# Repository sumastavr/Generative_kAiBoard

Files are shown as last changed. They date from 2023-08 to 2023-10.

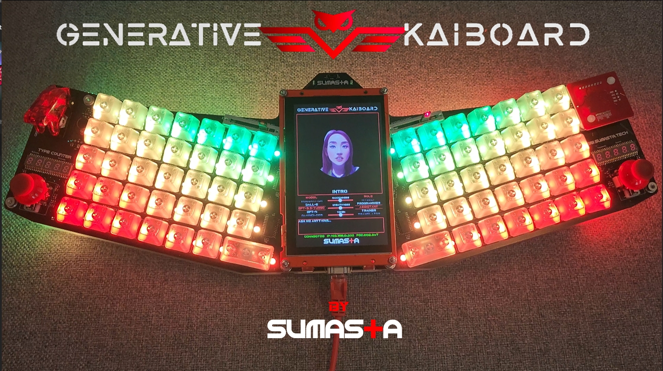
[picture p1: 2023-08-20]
Media/2023-08-20 00 04 33.jpg

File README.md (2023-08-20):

# Generative_kAiBoard 

"Introducing the "Generative KAiboard": a revolutionary fusion of cutting-edge technology and design. This keyboard redefines the boundaries of user interaction, boasting a plethora of advanced features, elegant design, AI-powered intelligence and virtual assistance that transcend traditional input devices. Crafted with an emphasis on aesthetics and functionality, the keyboard houses 70 Cherry MX switches with an impressive 100 million keystroke guarantee, ensuring both responsiveness and durability. Its versatility is highlighted by an array of 80 addressable pixel RGB LEDs, creating captivating lighting effects within a translucent 3D-printed housing.

The keyboard seamlessly integrates an 8x8 multizone time-of-flight sensor, ushering in a new era of presence and gesture detection. Additionally, a dedicated co-processor enables Bluetooth HID connections to various devices, while an NFC tag reader enhances security through authentication. Safety and security are paramount, with meticulous considerations in the PoE design ensuring consistent and reliable power delivery.

The "Generative KAiboard" transcends conventional interfaces, featuring a mono speaker for audio feedback and alerts. Its centerpiece is a 5-inch LCD display with a capacitive touch screen, offering a dynamic hub of information and interaction. Complemented by 60 RGB LEDs along the sides, the keyboard creates an enchanting symphony of light diffused through its translucent housing. The integration of a Wiznet W5300 shield and STM32F429 Nucleo board ensures future-proof modularity, enabling seamless upgrades and adaptability to evolving technologies. This extraordinary convergence of innovation, design, and intelligence marks the dawn of the "Generative KAiboard," a catalyst for the next generation of human-computer interaction." - Generative kAiboard.











The journey of crafting the Generative kAiboard has been an extraordinary endeavor that encapsulates both passion and persistence. Within a span of just five weeks, fueled by countless sleepless nights and unwavering dedication, I have breathed life into this intricate creation. The process has been a fusion of technical prowess and artistic inspiration, resulting in a masterpiece that harmoniously blends cutting-edge technology with a touch of imagination.

Every line of code, every connection meticulously soldered, every sleep-deprived night spent fine-tuning details – all of these have converged to birth a tangible manifestation of innovation. The Generative kAiboard is not just a keyboard; it's a testament to the capabilities of human creativity and the relentless pursuit of turning imagination into reality. As I now present the culmination of this journey, I invite you to explore, experiment, and immerse yourself in the possibilities this keyboard offers. With each keystroke, may it remind you of the remarkable journey it took to bring this vision to life – a journey characterized by determination, sleepless nights, and the sheer joy of creation.

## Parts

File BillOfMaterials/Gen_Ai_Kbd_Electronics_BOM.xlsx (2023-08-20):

Line # | Name | Description | Designator | Revision ID | Revision Status | Quantity | Ordered Status | Manufacturer 1 | Manufacturer Part Number 1 | Manufacturer Lifecycle 1 | Supplier 1 | Supplier Part Number 1 | Supplier Unit Price 1 | Supplier Subtotal 1
 | 885012206114 | WCAP-CSGP Multilayer Ceramic Chip Capacitor, General Purpose, size 0603, X7R, 10nF, 100VDC | C1 | CMP-007-000667-1 | Up to date | 1 | Stock
 | 885012008079 | WCAP-CSGP Multilayer Ceramic Chip Capacitor, General Purpose, size 1206, NP0, 10nF, 100VDC | C2, C3 | CMP-007-000324-1 | Up to date | 2 | Stock
 | 875575357008 | 875575357008 Cap, 470Uf, 16V, Alu Elec, Hybrid, Smd Rohs Compliant: Yes |Wurth Elektronik 875575357008 | C4, C10 | CMP-03913-134709151-1 | Up to date | 2 | Ordered 4 | Wurth Electronics | 875575357008 | Unknown | Digi-Key | 732-875575357008CT-ND | 3.19 | 6.38
 | 885012206095 | WCAP-CSGP Multilayer Ceramic Chip Capacitor, General Purpose, size 0603, X7R, 100nF, 50VDC | C5, C11, C13, C47, C51, C52, C53, C54, C57, C58, C59, C61, C63, C65, C67, C69, C70, C71, C72, C74, C76, C79, C81 | CMP-007-000655-1 | Up to date | 23 | Stock
 | 885012206020 | WCAP-CSGP Multilayer Ceramic Chip Capacitor, General Purpose, size 0603, X7R, 100nF, 10VDC | C6, C7, C8, C9 | CMP-007-000576-1 | Up to date | 4 | Stock
 | 885012106006 | WCAP-CSGP Multilayer Ceramic Chip Capacitor, General Purpose, size 0603, X5R, 10µF, 6.3VDC | C12, C46, C60, C62, C64, C66, C68, C75, C77, C80, C82 | CMP-007-000403-1 | Up to date | 11 | Stock
 | 885012205018 | WCAP-CSGP Multilayer Ceramic Chip Capacitor, General Purpose, size 0402, X7R, 100nF, 10VDC | C14, C15, C16, C17, C18, C19, C20, C21, C22, C23, C24, C25, C26, C27, C28, C29, C30, C31, C32, C33, C34, C35, C36, C37, C38, C39, C40, C41, C42, C43 | CMP-007-000501-1 | Up to date | 30 | Stock
 | 885012206051 | 885012206051 Cap Cer 0.68UF 16V X7R 0603 | C44, C45, C48, C55, C56, C73, C78, C84 | CMP-03913-53914760-1 | Up to date | 8 | Stock | Wurth Electronics | 885012206051 | Volume Production | Farnell | 2534025 | 0.07158 | 0.71579
 | 885342211008 | 885342211008 4700PF 2000V X7R 1812 10% - Multilayer Ceramic Capacitors | C49, C50, C83 | CMP-03913-89205791-1 | Up to date | 3 | Ordered 9 | Wurth Electronics | 885342211008 | Unknown | Farnell | 2812616 | 0.78494 | 2.35
 | ABS10A-13 | BRIDGE RECT 1PHASE 1KV 1A 4SOPA | D1, D3 | CMP-12791-000054-1 | Up to date | 2 | Cart Digikey 14 | Diodes | ABS10A-13 | Unknown | Arrow Electronics | ABS10A-13 | 0.2889 | 0.5778
 | 824541581 | 824541581 TVS diode [Würth Elektronik] 824541581 TVS diode | D2 | CMP-03913-71101705-1 | Up to date | 1 | Ordered 4 | Wurth Electronics | 824541581 | Volume Production | Digi-Key | 732-9823-1-ND | 0.89 | 0.89
 | 824045817 | 824045817 Tvs Diode, Unidir, 7V, Dfn1610 Rohs Compliant: Yes |Wurth Elektronik 824045817 | D4, D5, D6, D7, D8, D9, D10, D11, D12, D13, D14, D15, D16 | CMP-03913-128281014-1 | Up to date | 13 | Ordered 20 | Wurth Electronics | 824045817 | Unknown | Mouser | 710-824045817 | 0.567 | 7.37
 | 1N4148WS | DIODE GEN PURP 75V 150MA SOD323F | D17, D21, D22 | CMP-07163-000040-1 | Up to date | 3 | Cart Digikey 25 | ON Semiconductor / Fairchild | 1N4148WS | Volume Production | Newark | 08AK7787 | 0.022 | 0.066
 | 82400102 |  | D18 | CMP-1486-00007-2 | Up to date | 1 | Ordered 4 | Wurth Electronics | 82400102 | Volume Production | Mouser | 710-82400102 | 0.85 | 0.85
 | 155124M172400 | 155124M172400 Wl-sfsw SMT Full-color Side View | D19, D20 | CMP-03913-133884675-1 | Up to date | 2 | Ordered 8 | Wurth Electronics | 155124M172400 | Unknown | Digi-Key | 732-155124M172400CT-ND | 0.58 | 1.16
 | 157102S12800 | 157102S12800 WL-S7DS 7 Segments Display SMT Single Digit | DS1, DS2, DS3, DS4, DS5, DS6, DS7, DS8, DS9, DS10 | CMP-03913-133884679-1 | Up to date | 10 | Ordered 14 | Wurth Electronics | 157102S12800 | Unknown | Digi-Key | 732-157102S12800CT-ND | 3.14 | 31.4
 | 74279246 | WE-CBF SMT EMI Suppression Ferrite Bead, size 1806, 1000Ohm, 1.5A | FB1, FB2, FB3, FB6, FB7, FB8 | CMP-021-000088-1 | Up to date | 6 | Ordered 10 | Wurth Electronics | 74279246 | Unknown | Digi-Key | 732-74279246CT-ND | 0.3 | 1.8
 | 742792907 |  | FB4 | CMP-0220-00071-2 | Up to date | 1 | Ordered 3 | Wurth Electronics | 742792907 | Volume Production | Mouser | 710-742792907 | 2.86 | 2.86
 | 7427927311 |  | FB5, FB9, FB14, FB28, FB29 | CMP-0220-00132-2 | Up to date | 5 | Ordered 10 | Wurth Electronics | 7427927311 | Volume Production | Digi-Key | 732-2366-1-ND | 0.18 | 0.9
 | 742792651 |  | FB10, FB11, FB15, FB16, FB17, FB18, FB19, FB20, FB21, FB22, FB23, FB24, FB25, FB26, FB27 | CMP-0220-00181-3 | Up to date | 15 | Ordered 20 | Wurth Electronics | 742792651 | Volume Production | Mouser | 710-742792651 | 0.18 | 2.7
 | 61003621821 |  | J1, J2, J4, J5 | CMP-1502-01300-2 | Up to date | 4 | Ordered 6 | Wurth Electronics | 61003621821 | Unknown
 | 629722000214 | Conenctor USB 2.0 Type C Horizontal SMT | J3, J11 | CMP-207978-000003-2 | Up to date | 2 | Ordered 4 | Wurth Electronics | 629722000214 | Unknown | Farnell | 4146212 | 2.91 | 5.82
 | 613002143121 |  | J6, J7 | CMP-1502-01405-2 | Up to date | 2 | NR | Wurth Electronics | 613002143121 | Unknown | Farnell | 3583858 | 0.32393 | 3.24
 | 613003143121 |  | J8 | CMP-1502-01406-2 | Up to date | 1 | NR | Wurth Electronics | 613003143121 | Unknown | Newark | 99AH1112 | 0.399 | 3.99
 | 62200421821 |  | J9, J10, J12 | CMP-1502-01179-2 | Up to date | 3 | NR | Wurth Electronics | 62200421821 | Unknown | Mouser | 710-62200421821 | 0.74 | 2.22
 | 74438367068 | 74438367068 Power Inductor, 6.8Uh, Shielded, 5.7A Rohs Compliant: Yes |Wurth Elektronik 74438367068 | L1 | CMP-03913-130924347-1 | Up to date | 1 | Ordered 4 | Wurth Electronics | 74438367068 | Unknown | Mouser | 710-74438367068 | 2.14 | 2.14
 | 744232090 |  | L2 | CMP-0222-00035-2 | Up to date | 1 | Ordered 4 | Wurth Electronics | 744232090 | Volume Production | Mouser | 710-744232090 | 1.28 | 1.28
 | NX8048P050-011C | Nextion 5.5 Inch LCD | LCD1 | CMP-00028-00007-2 | Up to date | 1 | Stock | B&F Fastener | MPMS0020012PH | Volume Production
 | ESP32-WROOM-DA | WiFi-Modul 802.11/BT 2, 4-2, 5GHz 150Mb/s, dual antenna | MD1 | CMP-021-00008-1 | Up to date | 1 | Cart Digikey 3 | Espressif Systems | ESP32-WROOM-32E(4MB) | Unknown
 | 7466003 | 7466003 WP-SMBU REDCUBE Bush, SMT_open | MP1, MP2, MP3, MP4, MP5, MP6, MP7, MP8, MP9 | CMP-03913-34964368-1 | Up to date | 9 | Ordered 10 | Wurth Electronics | 7466003 | Volume Production | Farnell | 2405984 | 2.23 | 22.32
 | 61300411121 |  | P1, P6 | CMP-1502-01064-2 | Up to date | 2 | NR | Wurth Electronics | 61300411121 | Volume Production | Digi-Key | 732-5317-ND | 0.19 | 0.38
 | 61003621121 |  | P2, P3, P4, P5 | CMP-1502-01049-2 | Up to date | 4 | Ordered 6 | Wurth Electronics | 61003621121 | Volume Production | Mouser | 710-61003621121 | 5.25 | 21
 | 140356145000 | 140356145000 Optocoupler, Transistor, 80V, Sop-4 Rohs Compliant: Yes |Wurth Elektronik 140356145000 | Q1 | CMP-03913-114060666-1 | Up to date | 1 | Ordered 4 | Wurth Electronics | 140356145000 | Unknown | Farnell | 3619699 | 0.35304 | 0.35304
 | UMH3NTN | TRANS 2NPN PREBIAS 0.15W UMT6 | Q2 | CMP-08979-000010-1 | Up to date | 1 | Cart Digikey 10 | Rohm | UMH3NTN | Volume Production | Mouser | 755-UMH3NTN | 0.45 | 0.45
 | BSS123-7-F | MOSFET N-CH 100V 170MA SOT23-3 | Q3, Q4 | CMP-12801-000017-1 | Up to date | 2 | Cart Digikey 15 | Diodes | BSS123-7-F | Volume Production | Mouser | 621-BSS123-F | 0.26 | 0.52
 | RC0603FR-070RL | RES SMD 0 OHM JUMPER 1/10W 0603 | R1, R2, R8, R45, R46 | CMP-2000-06925-2 | Up to date | 5 | Stock | Yageo | RC0603FR-070RL | Volume Production | Newark | 50Y7761 | 0.002 | 0.01
 | RKJXK122400Y | Res POT 10K Ohm 0.0125W (25.4 X 20.7 X 19.3mm) Pin Bracket Mount/Through Hole Tray | R3, R4 | CMP-24118-000005-1 | Up to date | 2 | Cart Mouser | Alps Electric | RKJXK122400Y | Volume Production
 | RC0603FR-07470RL | General Purpose Chip Resistor, 470 Ohm, +/- 1%, -55 to 155 degC, 0603 (1608 Metric), RoHS, Tape and Reel | R5, R6 | CMP-1659-00035-2 | Up to date | 2 | Stock | Yageo | RC0603FR-07470RL | Volume Production | Newark | 75X0155 | 0.003 | 0.006
 | Resistor 10k +/-1% 0603 100 mW | Chip Resistor, 10 KOhm, +/- 1%, 01 W, -55 to 155 degC, 0603 (1608 Metric) | R7, R9, R10, R11, R12, R13, R14, R15, R16, R17, R18, R19, R20, R21, R22, R23, R24, R25, R26, R27, R28, R29, R30, R31, R32, R33, R34, R35, R36, R37, R38, R39, R40, R41, R42, R43, R44, R47, R48, R49, R50 | CMP-009-00017-5 | Up to date | 41 | Stock | Yageo | RC0603FR-0710KL | Volume Production | Newark | 68X3181 | 0.003 | 0.123
 | RC0603FR-075K1L |  | R51, R52, R53, R54 | CMP-2000-04091-1 | Up to date | 4 |  | Yageo | RC0603FR-075K1L | Volume Production | Avnet | 82AH8175 | 0.004 | 0.016
 | YC164-JR-0710KL | RES ARRAY 4 RES 10K OHM 1206 | RN1, RN2, RN3, RN4 | CMP-03411-000003-1 | Up to date | 4 | Cart Digikey 100 | Yageo | YC164-JR-0710KL | Volume Production | Digi-Key | YC164J-10KCT-ND | 0.1 | 0.4
 | EXB-2HV101JV | RES ARRAY 8 RES 100 OHM 1506 | RN5, RN6, RN7, RN8, RN9, RN10, RN11, RN12, RN13, RN14 | CMP-05421-000005-1 | Up to date | 10 | Cart Digikey 25 | Panasonic | EXB-2HV101JV | Volume Production | Farnell | 2060071 | 0.13345 | 1.33
 | MX1A-11NW | Switch Key N.O. SPST 0.01A 12VAC 12VDC 0.58N PC Pins 50000000Cycles Thru-Hole | SW1, SW2, SW3, SW4, SW5, SW6, SW7, SW8, SW9, SW10, SW11, SW12, SW13, SW14, SW15, SW16, SW17, SW18, SW19, SW20, SW21, SW22, SW23, SW24, SW25, SW26, SW27, SW28, SW29, SW30, SW31, SW32, SW33, SW34, SW35, SW36, SW37, SW38, SW39, SW40, SW41, SW42, SW43, SW44, SW45, SW46, SW47, SW48, SW49, SW50, SW51, SW52, SW53, SW54, SW55, SW56, SW57, SW58, SW59, SW60, SW61, SW62, SW63, SW64, SW65, SW66, SW67, SW68, SW69, SW70 | CMP-011-00013-1 | Up to date | 70 | Stock | Cherry | MX1A-11NW | Volume Production | Mouser | 540-MX1A-11NW | 0.776 | 54.32
 | 7499411122A | 7499411122A Rj45 Conn, R/A Jack, 8P8C, 1Port, Th Rohs Compliant: Yes |Wurth Elektronik 7499411122A | T1 | CMP-03913-82944263-1 | Up to date | 1 | Ordered 3 | Wurth Electronics | 7499411122A | Unknown | Mouser | 710-7499411122A | 14.77 | 14.77
 | AG5405 | PoE Module 802.3at | U1 | CMP-019-00052-1 | Up to date | 1 | Cart Mouser | STMicroelectronics | L7805CV-DG | Volume Production | Future Electronics | 8013057 | 0.44 | 0.44
 | CD74HC4067M96 | IC MUX/DEMUX 1X16 24SOIC | U2, U3, U4, U5 | CMP-04901-000007-1 | Up to date | 4 | Cart Mouser | Texas Instruments | CD74HC4067M96 | Volume Production
 | 173950336 | 173950336 WPME-FDSM Fixed Step Down Regulator Module | U6 | CMP-03913-104891430-1 | Up to date | 1 | Ordered 3 | Wurth Electronics | 173950336 | Unknown | Mouser | 710-173950336 | 6.52 | 6.52
 | NUCLEO-F429ZI | STM32F429ZI, mbed-Enabled Development Nucleo-144 STM32F4 ARMÂ® CortexÂ®-M4 MCU 32-Bit Embedded Evaluation Board | U7 | CMP-017-000000-2 | Up to date | 1 | Stock
 | CP2104-F03-GM | IC SGL USB-TO-UART BRIDGE 24QFN | U8 | CMP-0511-00004-2 | Up to date | 1 | Cart Digikey 3 | Silicon Labs | CP2104-F03-GM | Volume Production | Arrow Electronics | CP2104-F03-GM | 2.94 | 2.94
 | SN74LV1T125DBVR | Single Power Supply, Single BUFFER GATE w/ 3-State Output (active low enable), DBV0005A, LARGE T&R | U9, U10, U22, U24, U25 | CMP-0859-00122-3 | Up to date | 5 | Cart Digikey 15 | Texas Instruments | SN74LV1T125DBVR | Volume Production | Arrow Electronics | SN74LV1T125DBVR | 0.5289 | 2.64
 | 74HC595PW,118 | IC SHIFT REGISTER 8BIT 16TSSOP | U11, U13, U14, U15, U16, U17, U18, U19, U20, U21 | CMP-14351-000004-1 | Up to date | 10 | Cart Mouser | Nexperia | 74HC595PW,118 | Volume Production | Newark | 26AC8674 | 0.128 | 1.28
 | VL53L5CX | VL53L5CX - 8X8 Segment, Light, 3D Time-of-Flight _ToF_ Sensor Evaluation Board | U12 | CMP-003-000011-1 | Up to date | 1 | Cart Mouser
 | 24LC1025-I/SM | 1 Mbit, 400kHz, 2.5V, I2C Serial EEPROM, 8-Pin SOIC 208mil, Industrial Temperature | U23 | CMP-0159-00567-1 | Up to date | 1 | Cart Mouser | Microchip | 24LC1025-I/SM | Volume Production | Mouser | 579-24LC1025-I/SM | 3.83 | 3.83
 | PTL30-15R0-103B1 | Linear Trimpot(R) Trimming Potentiometer, 10 KOhm, +/- 10%, 0.5 W, -55 to 125 degC, 3-Pin THD, RoHS, Tube | VR1, VR2 | CMP-009-00177-1 | Up to date | 2 | Cart Digikey 4 | Bourns | 3296W-1-103LF | Volume Production | Arrow Electronics | 3296W-1-103LF | 1.65 | 3.29
 | 1655 | NeoPixel 5050 RGB LED with Integrated Driver Chip - 10 Pack | W1, W2, W3, W4, W5, W6, W7, W8, W9, W10, W11, W12, W13, W14, W15, W16, W17, W18, W19, W20, W21, W22, W23, W24, W25, W26, W27, W28, W29, W30, W31, W32, W33, W34, W35, W36, W37, W38, W39, W40, W41, W42, W43, W44, W45, W46, W47, W48, W49, W50, W51, W52, W53, W54, W55, W56, W57, W58, W59, W60, W61, W62, W63, W64, W65, W66, W67, W68, W69, W70, W71, W72, W73, W74, W75, W76, W77, W78, W79, W80 | CMP-00026-00001-1 | Up to date | 80 | Stock | Adafruit Industries | 1655 | Volume Production | Mouser | 485-1655 | 4.5 | 360

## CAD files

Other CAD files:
Mechanics/Siemens NX/Keyboard housing_20230808.prt

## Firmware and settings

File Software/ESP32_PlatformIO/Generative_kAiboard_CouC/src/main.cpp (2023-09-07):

#include <Arduino.h>
#include <FastLED.h>
#include <BleKeyboard.h>
#include <EEPROM.h>

#define LEDCHANGEHEADER     212
#define LEDCHANGEFOOTER     213

#define LEDSLEEPMODEHEADER  215
#define LEDSLEEPMODEFOOTER  216

#define KBDPRESSCODE        201
#define KBDRELEASECODE      202

#define STREAMSTARTCODE     221
#define STREAMDONECODE      222

SET_LOOP_TASK_STACK_SIZE(16*1024);

// RGB Shades data output to LEDs is on pin 5
#define LED_PIN  13

// RGB Shades color order (Green/Red/Blue)
#define COLOR_ORDER GRB
#define CHIPSET     WS2811

// Global maximum brightness value, maximum 255
#define MAXBRIGHTNESS 255
#define STARTBRIGHTNESS 25

// Cycle time (milliseconds between pattern changes)
#define cycleTime 7000

// Hue time (milliseconds between hue increments)
#define hueTime 30

// Time after changing settings before settings are saved to EEPROM
#define EEPROMDELAY 2000

#include "messages.h"
#include "font.h"
#include "XYmap.h"
#include "utils.h"
#include "effects.h"

// list of functions that will be displayed
functionList effectList[] = { threeDee,
                              plasma,
                              threeSine,
                              confetti,
                              rider,
                              glitter,
                              slantBars,
                              colorFill,
                              sideRain,
                            };


const byte numEffects = (sizeof(effectList)/sizeof(effectList[0]))-1;
//const byte numEffects=4;

BleKeyboard bleKeyboard("Generative kAiboard","Sumasta-Tech",100);

#define PIN_JYS_L_Y   32
#define PIN_JYS_L_X   15
#define PIN_JYS_L_BUT 4

#define PIN_JYS_R_Y   14
#define PIN_JYS_R_X   12
#define PIN_JYS_R_BUT 35

#define PIN_SLD_L     27
#define PIN_SLD_R     26

#define PORT_LED_SLD_L  23
#define PORT_LED_SLD_R  22

void setup() {
  pinMode(21,OUTPUT);
  digitalWrite(21,LOW);

  pinMode(PIN_JYS_L_Y,INPUT);
  pinMode(PIN_JYS_L_X,INPUT);
  pinMode(PIN_JYS_L_BUT,INPUT_PULLUP);
  
  pinMode(PIN_JYS_R_Y,INPUT);
  pinMode(PIN_JYS_R_X,INPUT);
  pinMode(PIN_JYS_R_BUT,INPUT_PULLUP);

  pinMode(PIN_SLD_L,INPUT);
  pinMode(PIN_SLD_R,INPUT);

  pinMode(PORT_LED_SLD_L,OUTPUT);
  pinMode(PORT_LED_SLD_R,OUTPUT);
  
  Serial.begin(115200);
  Serial2.begin(115200);
  
  //FastLED.addLeds<WS2812, DATA_PIN, RGB>(leds, NUM_LEDS);
  //FastLED.setBrightness(scale8(currentBrightness, MAXBRIGHTNESS));
  FastLED.addLeds<CHIPSET, LED_PIN, COLOR_ORDER>(leds, LAST_VISIBLE_LED + 1);

  Serial.println(ESP.getFreeHeap());
  bleKeyboard.begin();

}

long readADCTimer=millis();

long readBrightnessSetTimer=millis();
int intervalReadBrightness=100;

void checkBrightness();

int lastMappedBrightness=0;
int currentMappedBrightness=0;

bool sleepMode=false;
bool stramingResult=false;

void checkBrightness(){

  currentMappedBrightness=map(analogRead(PIN_SLD_L),0,4095,0,MAXBRIGHTNESS);
  if(currentMappedBrightness!=lastMappedBrightness && !sleepMode){
    #ifdef FULL_DEBUG
      Serial.println("New Brightness: ");
      Serial.println(currentMappedBrightness);
    #endif
    FastLED.setBrightness(scale8(currentMappedBrightness,MAXBRIGHTNESS));
  }
  lastMappedBrightness=currentMappedBrightness;

}

bool toggleLEDSlider=false;

long timerToggleLED=millis();
int intervalTimerToggleLED=500;

void toggleSliderLED(){

  toggleLEDSlider=!toggleLEDSlider;
  digitalWrite(PORT_LED_SLD_R,toggleLEDSlider);
  digitalWrite(PORT_LED_SLD_L,!toggleLEDSlider);  

}

long readModeLightTimer=millis();
int intervalReadModeLightTimer=0;
byte currentLightModeSelection=0;
byte lastLightModeSelection=0;

void checkModeLight(){
  currentLightModeSelection=map(analogRead(PIN_SLD_R),0,4095,0,numEffects);
  if(currentLightModeSelection!=lastLightModeSelection){
    effectInit = false;
    currentEffect=currentLightModeSelection;
  }
  lastLightModeSelection=currentLightModeSelection;
}

long readLeftJoystickTimer=millis();
int readLeftJoystickInterval=250;
const int thresholdHigh=3500;
const int thresholdLow=1000;

void checkLeftJoystick(){
  int xValue=analogRead(PIN_JYS_L_X);
  int yValue=analogRead(PIN_JYS_L_Y);
  bool button=digitalRead(PIN_JYS_L_BUT);

  if(yValue>thresholdHigh){
    bleKeyboard.write(KEY_MEDIA_VOLUME_DOWN);
  }else if(yValue<thresholdLow){
    bleKeyboard.write(KEY_MEDIA_VOLUME_UP);
  }

  if(xValue>thresholdHigh){
    bleKeyboard.write(KEY_MEDIA_NEXT_TRACK);
    delay(500);
  }else if(xValue<thresholdLow){
    bleKeyboard.write(KEY_MEDIA_PREVIOUS_TRACK);
    delay(500);
  }

  if(button==LOW){
    bleKeyboard.write(KEY_MEDIA_PLAY_PAUSE);
    delay(500);
  }
  
}

long readRightJoystickTimer=millis();
int readRightJoystickInterval=100;

void checkRightJoystick(){
  int xValue=analogRead(PIN_JYS_R_X);
  int yValue=analogRead(PIN_JYS_R_Y);
  bool button=digitalRead(PIN_JYS_R_BUT);

  if(xValue>thresholdHigh){
    bleKeyboard.write(KEY_DOWN_ARROW);
  }else if(xValue<thresholdLow){
    bleKeyboard.write(KEY_UP_ARROW);
  }

  if(yValue>thresholdHigh){
    bleKeyboard.write(KEY_RIGHT_ARROW);
  }else if(yValue<thresholdLow){
    bleKeyboard.write(KEY_LEFT_ARROW);
  }

  /*
  if(button==LOW){
    bleKeyboard.write(KEY_MEDIA_PLAY_PAUSE);
    delay(500);
  }
  */
  
}


void loop() {

  if(millis()-timerToggleLED>intervalTimerToggleLED){
    toggleSliderLED();
    timerToggleLED=millis();
  }

  if(millis()-readBrightnessSetTimer>intervalReadBrightness){
    checkBrightness();
    readBrightnessSetTimer=millis();
  }

  if(millis()-readModeLightTimer>intervalReadModeLightTimer){
    checkModeLight();
    readModeLightTimer=millis();
  }

  if(millis()-readLeftJoystickTimer>readLeftJoystickInterval){
    checkLeftJoystick();
    readLeftJoystickTimer=millis();
  }

  if(millis()-readRightJoystickTimer>readRightJoystickInterval){
    checkRightJoystick();
    readRightJoystickTimer=millis();
  }

  currentMillis = millis(); // save the current timer value

  // switch to a new effect every cycleTime milliseconds
  if (currentMillis - cycleMillis > cycleTime && autoCycle == true && currentLightModeSelection==0) {
    cycleMillis = currentMillis;
    effectInit = false;
    if(++currentEffect>numEffects)currentEffect=0;
  }

  // increment the global hue value every hueTime milliseconds
  if (currentMillis - hueMillis > hueTime) {
    hueMillis = currentMillis;
    hueCycle(1); // increment the global hue value
  }

  // run the currently selected effect every effectDelay milliseconds
  if (currentMillis - effectMillis > effectDelay) {
    effectMillis = currentMillis;
    effectList[currentEffect](); // run the selected effect function
    random16_add_entropy(1); // make the random values a bit more random-ish
  }

  // run a fade effect too if the confetti effect is running
  if (effectList[currentEffect] == confetti) fadeAll(1);

  if(!sleepMode){
    FastLED.show(); // send the contents of the led memory to the LEDs
    FastLED.delay(10);
  }

  if(bleKeyboard.isConnected()) {

    while(Serial2.available()>0){
      byte in=Serial2.read();
      if(in==LEDCHANGEHEADER){
        Serial.println("LED Change");
        delay(5);
        byte lightMode=Serial2.read();
        if (lightMode>=49 && lightMode <=57){
          lightMode-=48;
          Serial.println(lightMode);
          effectInit = false;
          currentEffect=lightMode;
          Serial2.flush();
        }
      }else if(in==LEDSLEEPMODEHEADER){
        Serial.println("SLEEP MODE Command");
        delay(5);
        byte enableLED=Serial2.read();
        if (enableLED>=48 && enableLED <=50){
          //enableLED-=48;
          Serial.println(enableLED);
          if(enableLED==49){
            FastLED.setBrightness(0);
            FastLED.show(); 
            sleepMode=true;
          }else if(enableLED==48){
            FastLED.setBrightness(scale8(currentMappedBrightness,MAXBRIGHTNESS));
            sleepMode=false;
          }
          Serial2.flush();
        }
      }else if(in==KBDPRESSCODE){
        delay(5);
        byte key=Serial2.read();
        bleKeyboard.press(char(key));
        Serial.print("PRESS: "); 
        Serial.println(char(key));
      }else if(in==KBDRELEASECODE){
        delay(5);
        byte key=Serial2.read();
        bleKeyboard.release(char(key));
        Serial.print("RELEASE: "); 
        Serial.println(char(key));
      }else if(in==STREAMSTARTCODE){
        Serial.flush();
        delay(200);
        while(Serial.available()>0)Serial.read();
        delay(300);        
        stramingResult=true;
      }else if(in==STREAMDONECODE){
        delay(5);
        Serial.flush();
        stramingResult=false;
      }else{
        Serial.write(in);
        //if(in<128){
        //  bleKeyboard.print(char(in));
        //}
        //bleKeyboard.write(in);
      }
    }

    while(Serial.available()>0 && stramingResult){
      byte in=Serial.read();
      if(in<128){
          bleKeyboard.write(in);
      }
    }

  }
}

/*
  if(millis()-readADCTimer>500){

    Serial.print(analogRead(PIN_JYS_L_Y));
    Serial.print('\t');
    Serial.print(analogRead(PIN_JYS_L_X));
    Serial.print('\t');
    
    Serial.print(analogRead(PIN_JYS_R_Y));
    Serial.print('\t');
    Serial.print(analogRead(PIN_JYS_R_X));
    Serial.print('\t');

    Serial.print(analogRead(PIN_SLD_L));
    Serial.print('\t');
    Serial.print(analogRead(PIN_SLD_R));
    Serial.print('\t');

    Serial.print(digitalRead(PIN_JYS_L_BUT));
    Serial.print('\t');
    Serial.print(digitalRead(PIN_JYS_R_BUT));
    Serial.println('\t');
    
    int brightness=map(analogRead(PIN_SLD_L),0,4095,0,255);
    FastLED.setBrightness(brightness);

    toggle=!toggle;

    digitalWrite(PORT_LED_SLD_R,toggle);
    digitalWrite(PORT_LED_SLD_L,!toggle);
    
    readADCTimer=millis();

  }
  */

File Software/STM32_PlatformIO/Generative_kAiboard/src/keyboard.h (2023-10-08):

/*

BSD 3-Clause License

Copyright (c) 2023, Pamungkas Sumasta (www.sumasta.tech)

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
1. Redistributions of source code must retain the above copyright notice, this
   list of conditions and the following disclaimer.

2. Redistributions in binary form must reproduce the above copyright notice,
   this list of conditions and the following disclaimer in the documentation
   and/or other materials provided with the distribution.

3. Neither the name of the copyright holder nor the names of its
   contributors may be used to endorse or promote products derived from
   this software without specific prior written permission.

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
*/

#include <Arduino.h>
#include "GPIO.h"
#include "keyboard_map.h"

const uint8_t MUX_CTRL_PORTS[] = {PORT_MUX_CTRL_S0, PORT_MUX_CTRL_S1, PORT_MUX_CTRL_S2, PORT_MUX_CTRL_S3};
const uint8_t MUX_READ_PINS[] = {PIN_KBD_L_MUX_1,PIN_KBD_L_MUX_2,PIN_KBD_R_MUX_1,PIN_KBD_R_MUX_2};

boolean keyStates[16][4];
boolean prevKeyStates[16][4];
boolean specialKeys[6];
boolean prevSpecialKeys[6];

const uint8_t scanIteration=16;

uint32_t clickCounter=0;
long timerSaveKeycount=millis();
long intervalSaveKeycount=1800000;

bool currentKeyState=false;
bool currentSpKeyState=false;

void initVariables(){
  for (int i=0;i<16;i++){
    for (int x=0;x<4;x++){
      keyStates[i][x]=1;
      prevKeyStates[i][x]=1;
    }
  }
  for (int i=0;i<6;i++){
    specialKeys[i]=1;
    prevSpecialKeys[i]=1;
  }
}

void setTypeCounterBrightness(int value){
    analogWrite(PORT_7S_ENABLE,value);
}

void displayTypeCounter(uint32_t clickCount){
  
  int numberArray[10];

  digitalWrite(PORT_7S_STCP,LOW);
  for (int i=0;i<10;i++){
    numberArray[i]=clickCount%10; 
    clickCount=clickCount/10;
    shiftOut(PORT_7S_DS, PORT_7S_SHCP, MSBFIRST, digits_7s[numberArray[i]]);
  }
  digitalWrite(PORT_7S_STCP,HIGH);

}

char scanKeyboard(){

  // Scan through all possible MUX combination from S0 to S3
  for (uint8_t i=0;i<scanIteration;i++){

    // Write each of the MUX control based on the bit inputs
    for (uint8_t x=0; x<sizeof(MUX_CTRL_PORTS); x++){
      digitalWrite(MUX_CTRL_PORTS[x],bitRead(i,x));
    }

    for (uint8_t z=0;z<sizeof(MUX_READ_PINS);z++){

      bool pinState=digitalRead(MUX_READ_PINS[z]);
      keyStates[i][z]=pinState;
      currentKeyState=false;

        if(pinState!=prevKeyStates[i][z]){
          prevKeyStates[i][z]=keyStates[i][z];

          if(pinState){
            Serial.print("R: ");
            Serial.println(caseMux[i][z]);
            currentKeyState=false;
            prevKeyStates[i][z]=keyStates[i][z];
            return caseMux[i][z];
          }else{

            //Serial.print(" STATE: ");
            //Serial.print(i);
            //Serial.print(" MUX: ");
            //Serial.println(z);
            //delay(200);

            Serial.print("P: ");
            Serial.println(caseMux[i][z]);
            currentKeyState=true;
            prevKeyStates[i][z]=keyStates[i][z];
            displayTypeCounter(++clickCounter);
            return caseMux[i][z];
          }      
        }

      prevKeyStates[i][z]=keyStates[i][z];
    }
  }
  return NULL;
}

int scanSpecialKeys(){

  specialKeys[0]=digitalRead(PIN_KBD_L_SPK_1);
  specialKeys[1]=digitalRead(PIN_KBD_L_SPK_2);
  specialKeys[2]=digitalRead(PIN_KBD_L_SPK_3);
  specialKeys[3]=digitalRead(PIN_KBD_R_SPK_1);
  specialKeys[4]=digitalRead(PIN_KBD_R_SPK_2);
  specialKeys[5]=digitalRead(PIN_KBD_R_SPK_3);

  currentSpKeyState=false;

  for (int i=0;i<6;i++){
    if (specialKeys[i]!=prevSpecialKeys[i]){
      if(specialKeys[i]==LOW){
        currentSpKeyState=true;
        displayTypeCounter(++clickCounter);
      }else{
        currentSpKeyState=false;
      }
      prevSpecialKeys[i]=specialKeys[i];
      return i;
    }
  }

  for (int i=0;i<6;i++){
    prevSpecialKeys[i]=specialKeys[i];
  }

  return 99;
}

bool isPrintableKey(char in){
  bool printable=true;
  for (int i=0;i<nonPrintableTotal;i++){
    if (nonPrintable[i]==in){
      printable=false;
      return printable;
    }
  }
  return printable;
}

void processKey(char in){
  if(in!=NULL){
    if(currentKeyState){
      pressChar(in);
    }else{
      releaseChar(in);
    }
    delay(20);
  }
}

void processKeyGPT(char in){
  if(isPrintableKey(in)){      
    if(currentKeyState){    
      appendTextLCD(INPUT_KBD,String(in));
      delay(100);
    }
  }
}

void processSpKeyGPT(char inSp){
  if(inSp<6){
    switch(inSp){
      case 5: 
        changeLightMode(LED_MODE_THREESINE);
        playVideo(VID_OUTRO,100);
        break;
      case 3: 
        clearTextLCD(INPUT_KBD);
        stopCurrentVideo();
        delay(200);
        break;  
      }
    }
}
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

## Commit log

2023-08-20 V1 Schematic with errata for the next version
2023-08-20 Version 1 the first HW build
    [BluetoothHID.SchDoc, Display.SchDoc, Gen_Ai_Kbd-Main.SchDoc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]
2023-08-20 full step file with PCB and housing
2023-08-20 Gerber Files for JLPCB, and cropped paste mask
2023-08-20 Snapshot current version, Still very crude
2023-08-20 Current version, still very crude
2023-09-01 add NX files
    [Keyboard housing_20230808.prt]
2023-09-01 added housing file
2023-09-02 adjusted filter function
2023-09-05 Add KBD release and press protocol
    implement release and press kbd functions for macro and non printable characters etc. finalized also the keyboard map now the entire kbd is utilized
2023-09-07 improve kbd streaming logic, fix bugs, add system text bar
    [Coprocessor.h, main.cpp, utils.h]
2023-09-07 improve streaming kbd logic, fix bugs,
    [main.cpp]
